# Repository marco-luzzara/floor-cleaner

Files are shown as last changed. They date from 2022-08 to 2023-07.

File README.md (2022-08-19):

# Floor Cleaner

This repo is made of 2 parts:

- the folder `app` contains the Python app to create and send the map for the cleaning
- the folder `cleaner` contains the C project for the STM32 Nucleo board that will take care of the cleaning procedure

---

## Protocol for Serial Communication

The app sends the map info through the `/dev/ttyACM0` serial device on Linux. These are the data sent throughout the procedure:

1. The character `&`, which represents the start (and the end) of the data flow
2. The number of rows in the grid
3. The character `|`, which is the separator character
4. The number of columns in the grid
5. The character `|`
6. From now on, every byte represents a cell in the grid, row by row from left to right: 
    - `1` stands for cell unavailable (to **not** clean)
    - `2` stands for cell that must be cleaned
    - `3` stands for the cleaner position (direction: up)
7. The character `&`

This is an example of data flow:

```
&3|4|211222231222&
```

For the following map:

```
░██░
░░░X
█░░░

░ = cell to clean
█ = cell to not clean
X = cleaner position
```

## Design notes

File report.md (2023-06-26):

# Floor Cleaner

The project consists of a floor cleaner, which is controlled by a Desktop Application. The user can draw a map on this app and the robot will try to go over each available cell in the map.

### Project Structure

The project root folder contains:

- The `app` folder with the Desktop application. Execute it with `./run.sh`
- The `cleaner` folder with the Nucleo board source code and the tests for the algorithm used. Note: the optimization level must be set to **2** (`-O2`): *Properties* -> *C/C++ Build* -> *Settings* -> *MCU GCC Compiler* -> *Optimization* -> Set to *Optimize more (-O2)*. The C standard used is **GNU11** (`-std=gnu11`): *Properties* -> *C/C++ Build* -> *Settings* -> *MCU GCC Compiler* -> *General* -> Set the Language standard to *GNU11 (...)*.

---

## Desktop Application

The Desktop application has been developped in Python with the support of PyQT6 for the graphical interface.

### Map Drawing
The map is represented by a grid of cells, each of these cover an area of 5cm * 5cm. There are 3 types of cells:

- UNAVAILABLE (grey in the grid): the cleaner should not go through it
- TO_CLEAN (blue in the grid): this cell must be cleaned in order to complete the cleaning procedure
- CLEANER_POSITION (black in the grid): the initial position of the cleaner

Initially, all cells are unavailable, but the user can mark them as to-clean by selecting them with a mouse press and release action. To place the cleaner in the map, search for the *Cleaner* label in the menu and then click on *Place Cleaner*. The next cell to be selected will be the cleaner position.

### Serial communication details
Once the map is ready, the user can connect the cleaner with an USB cable and go to *File* -> *Send* to start the sending procedure.

**Note**: it is important to connect the cleaner before opening the send dialog because it is initialized with the currently available ports:

```
from serial.tools import list_ports, list_ports_common

# ...

for i, serial_data in enumerate(list_ports.comports()):
    self._combo_box_serial.insertItem(
        i, serial_data.description, userData=serial_data)
```

After selecting the identifier for the Nucleo Board, the python app starts to transmit the bytes of the map with a baudrate of 9600.

### Map Transformation

The transmitted map is the smallest rectangle that includes all the to-clean cells in the grid. This means that there will never be a boundary row or column where all cells are unavailable.

Then the optimized grid is transformed into a matrix and each cell becomes a byte, in particular:

- UNAVAILABLE = 0x00
- TO_CLEAN = 0x01
- CLEANER_POSITION = 0x03

The 0x02 value does not exist yet but corresponds to the ALREADY_CLEANED value.

### Sending Protocol

In order for the map to be correctly interpreted by the Nucleo board, data are transmitted as bytes in the following order:

1. The character `&`, which represents the start (and the end) of the data flow
2. The number of rows in the map
3. The character `|`
4. The number of columns in the map
5. The character `|`
6. The map's cells, row by row from left to right
7. The character `&`

### Realtime Cleaning Window

Once the map has been sent, a new window opens, showing the drawn map. This map cannot be updated by the user, but is updated automatically by the messages that receives from the cleaner. After the user starts the cleaner, the latter will start sending messages about the new positions or obstacles on its way. See below for the messages format.

---

## Floor Cleaner

The cleaner will go through each to-clean cell in the received grid and avoids those that are marked as unavailable.

### Architecture and Components

During the development of the project, the architecture have changed. The main reason was to accomodate the window for the realtime updates of the cleaner.

The first architecture included the motors (wheels) and was externally power-sourced. It is described by this Fritzing schema:

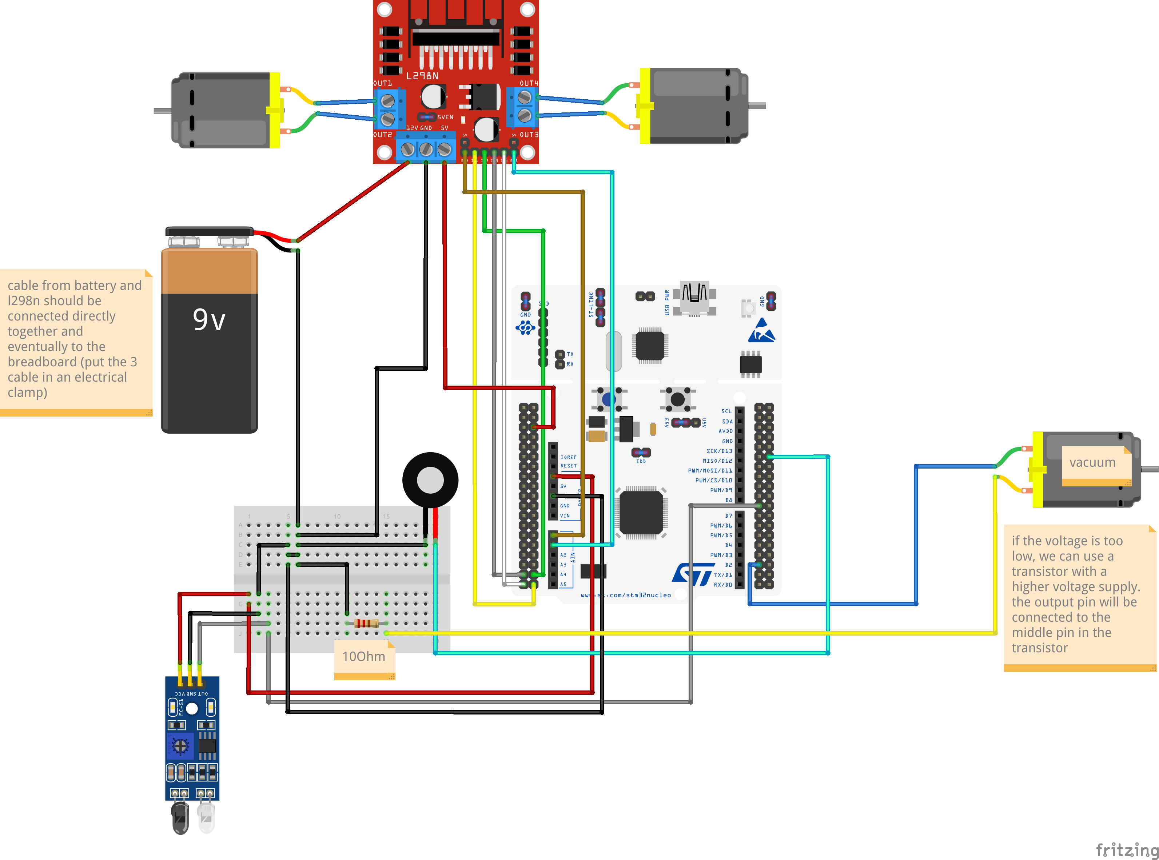
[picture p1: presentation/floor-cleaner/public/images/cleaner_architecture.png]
Architecture


#### Power Source
The power source consists of 2 batteries of 9V each, linked in parallel in order to increase the amperage. Each battery has an amperage of 1000mAh. Unfortunately, I have not found a light battery with a voltage of 12V, which would have increased the amount of components I could have added to the circuit.

#### L298N

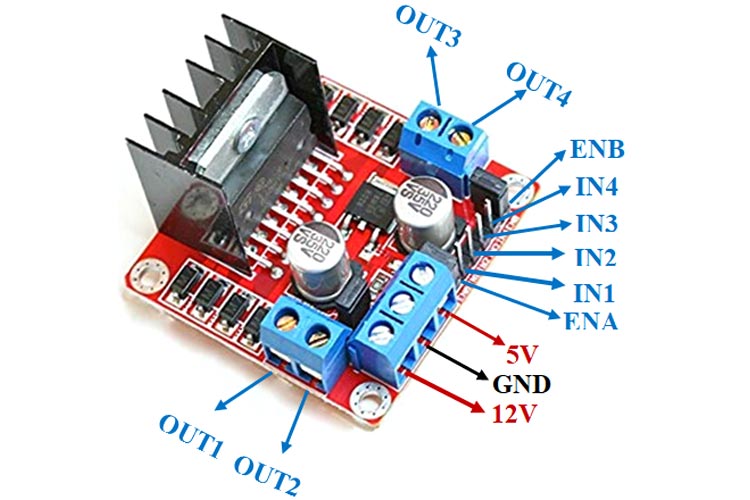
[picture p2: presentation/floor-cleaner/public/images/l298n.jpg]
L298N


This component is directly connected with the batteries and supplies power to:
- The 2 motors (wheels) using the output pins from OUT1 to OUT4
- The Nucleo board using the 5V pin, enabled via a jumper that regulates the input voltage

I can use the pins IN1-IN4 to control the motors direction, as described by the following table:

| IN1 | IN2 | Spinning direction |
| --- | --- | --- |
| 0 | 0 | Motor OFF |
| 0 | 1 | Backward |
| 1 | 0 | Forward |
| 1 | 1 | Motor OFF |

ENA and ENB are used to modulate the voltage that the output ports OUT1-OUT4 receive. These pins are connected to 2 PWM enabled pins, which are A0 and A1 in the Nucleo board.

#### IR Distance Sensor

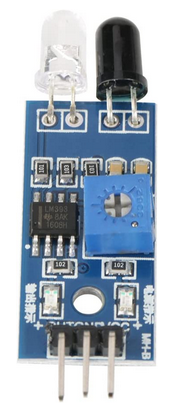
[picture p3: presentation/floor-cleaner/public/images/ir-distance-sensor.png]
IR distance sensor


The map is built by the user, but the cleaner might find some unpredictable obstacles on its way. To avoid any collisions, an IR distance sensor is used. This sensor has 3 pins:

- OUT: When a module detects an obstacle, the OUT port emits a low level signal that will be processed by the Nucleo board.
- GND
- VCC: this port is connected to the 3.3V pin of the Nucleo board

This component also has a potentiomenter that can adjust the IR sensor sensibility. Basically, it can detect obstacle from 2cm to 30cm, depending on the potentiometer value.

#### Buzzer

A buzzer informs the user about the cleaner's state:

- A single beep of 500ms: the cleaner is ready to receive a new map (and has successfully cleaned the previous map is present).
- 2 beeps of 500ms, interspersed by a beep of 300ms: the cleaner has received the map and is ready to drive
- 3 beeps of 300ms, interspersed by 2 beeps of 150ms: the cleaner has received an error while driving

---

### The Second Architecture 

The first architecture has some issues:

- The motors were not precise enough and a wheel could spin faster than the other. The motors were recycled from an old cleaner and each of them have a optical encoder mounted on it. I did not use it but it would have definitely improved the speed synchronization.
- 9V is probably too low to power-source the entire cleaner, the original battery was 14V.
- The window for realtime update was not possible because the cleaner moves freely and cannot be attached to the USB cable.

The second architecture is conceptually very similar to the previous one because the only difference is that it is power-sourced directly from the USB and the L298N connections have been replaced with LEDs. The only additional component is a LCD display that shows informational messages.

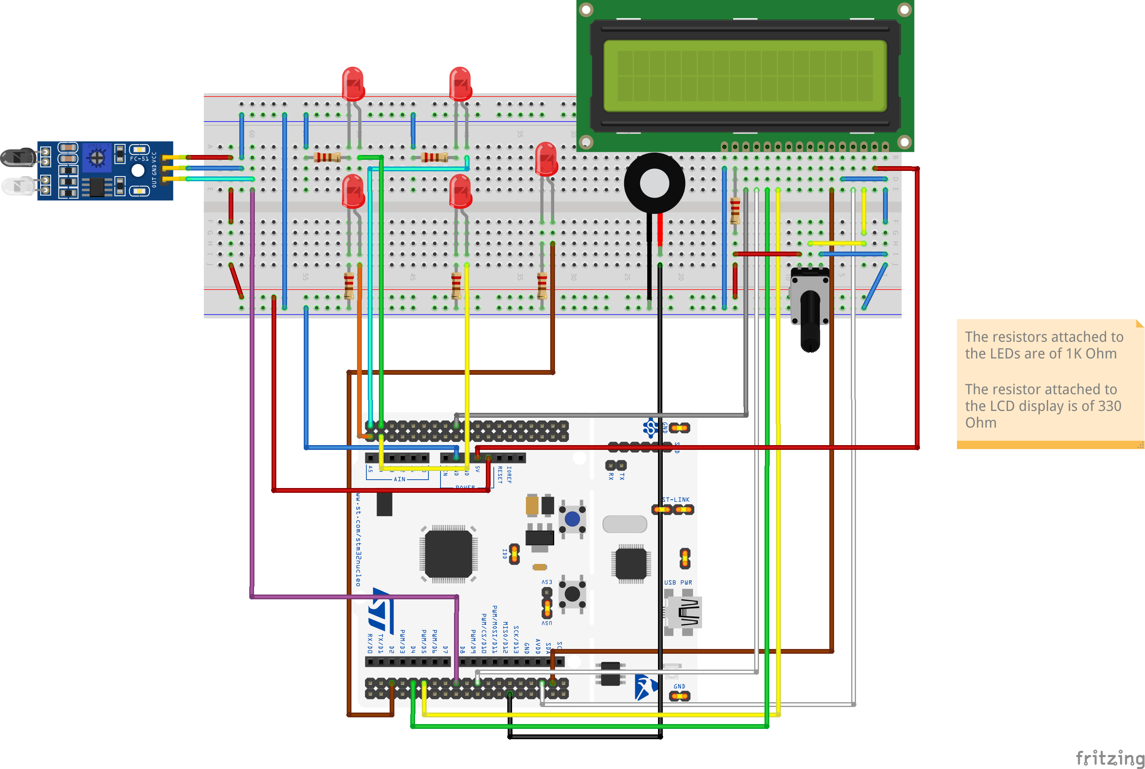
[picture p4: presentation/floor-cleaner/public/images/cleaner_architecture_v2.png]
Architecture v2


#### LCD Display

The LCD display is a 1602A LCD, that I have set on 4-bit mode. I have also used a potentiometer to adjust the screen brightness.

---

### Map Processing

The cleaner receives the map from the UART pin PA3. I have used the polling mode because the cleaner does not need to do anything else in the meanwhile.

The reading process is optimized to speed up the data saving. In fact, after reading the `row_count` and `column_count`, I allocate 2 arrays:

- `(CellType**) map_rows`: one of size `row_count` that contains the pointers to the map rows
- `(CellType*) map`: another one of size `row_count * column_count` containing the map cells

Assuming to have a map of 3 rows and 2 columns, this is how the 2 arrays are filled:

```

map:                                ┌───┬───┐
                      ┌───────────> │   │   │
                      │             ├───┼───┤
                      │   ┌───────> │   │   │
                      │   │         ├───┼───┤
                      │   │   ┌───> │   │   │
                      │   │   │     └───┴───┘
                      │   │   │
                      │   │   │
                      │   │   │
                    ┌───┬───┬───┐
map_rows:           │   │   │   │
                    └───┴───┴───┘
```

In this way, I can read the entire map at once by passing the `map` array as buffer. I am sure that the `map` array is a continuous block of memory, but I can access it through the `map_rows` array because it contains the pointers to the map rows.

The map data are placed in a struct of type `MapInfo`:

```
typedef struct MapInfo {
	uint8_t** map;
	uint16_t row_count;
	uint16_t column_count;
} MapInfo;
```

---

### Driving Preparation

Once the cleaner has received the entire map, the user can instruct the cleaner to start by pressing the user button on the Nucleo board. After about 1 second, the `start_drive` method is called and the cleaner will start driving:

```
HAL_TIM_Base_Start(&htim2); // Init PWM for motors' speed modulation
HAL_TIM_PWM_Start(&htim2, TIM_CHANNEL_1);
HAL_TIM_PWM_Start(&htim2, TIM_CHANNEL_2);

MotorsInfo motorsInfo = {
		.left1_GPIOType = MOTOR_1___IN1_GPIO_Port, .left1_pin = MOTOR_1___IN1_Pin,
        // ...
};
CleanComponentsInfo cleanComponentsInfo = { .vacuum_GPIOType = VACUUM_GPIO_Port, .vacuum_pin = VACUUM_Pin };
is_driving = true;
int result_code = start_drive(&mapInfo, &is_obstacle_found, &motorsInfo, &cleanComponentsInfo);
```

The `start_drive` method expects a list of struct that contains the components info, as well as a boolean flag, which is `is_obstacle_found`, that will be explained later.

As for the `result_code`, the only successful return code is 0, whereas the other are interpreted as error codes.

#### Cleaner Initialization

Before starting to clean, I initialize the `CleanerInfo` struct with its initial position in the map and its direction, that by default is `UP`. If the cleaner position cannot be found in the map, the `start_drive` returns 1.

#### Move Cleaner to the Start Position

For simplicity, the cleaner will always start cleaning from the top-left cell of the map, or to the one nearest to it if the top-left one is unavailable. The details on how the cleaner reaches the initial position are described later in the part dedicated to the driving algorithm.

If the initial position cannot be found or the cleaner cannot reach it, then the codes returned are 2 and 3, respectively.

---

### The Cleaning Algorithm

The cleaner will clean the entire area of the map starting from the top-left cell that must be clean and proceeding to the right. The logic is very simple: the cleaner will always maintain an unavailable cell on its left. In this way, it starts from the perimeter and progressively reaches the center of the area.

For the simplest case (a rectangle/square), the path that the cleaner follows is indicated by the dashed line:

```
┌───┬───┬───┬───┐
│ --│---│---│-┐ │
├───┼───┼───┼───┤
│ ┌-│---│-> │ │ │
├───┼───┼───┼───┤
│ └-│---│---│-┘ │
└───┴───┴───┴───┘
```

As far as the next cell to clean is adjacent to the current one, the next cell position can be easily computed by inspecting the surrounding cells. However, it is not always possible to have such a linear path, for example with this map:

```
┌───┬───┐   ┌───┬───┐
│---│-┐ │   │ ┌-│->?│
├───┼───┼───┼───┼───┘
│   │ └-│---│-┘ │
├───┼───┼───┼───┤
│   │   │   │   │
└───┴───┴───┴───┘
```

Once the cleaner reaches the top-right cell, there is no adjacent cell available. In this case, I need to search for the nearest reachable cell that is marked as to-clean, then I need a path-finding algorithm that can take the cleaner there.

The algorithm that looks for the nearest reachable cell firstly visit the square of cells that surround the current cell. If it does not find any to-clean cell, then it extends the radius of the square by 1 and so on until it finds a reachable cell (or until all the area has been cleaned). For example, in the following map:

```
┌───┬───┐   ┌───┬───┐
│ X │ X │   │ X │ C │
├───┼───┼───┼───┼───┘
│   │ X │ X │ X │
├───┼───┼───┼───┤
│   │   │   │ N │
└───┴───┴───┴───┘

C = cleaner
X = unavailable
N = next position
```

The target position (`N`) is the first one available while visiting the square of radius 2 from the cleaner position. In the next map I represented the order of visit of the cells around `C` (actually, some rows and columns are discarded in advanced, like those outside the map boundaries).

```
┌---┬---┬---┬---┬---┐
| 9 | 10| 11| 12| 13|
├---┼---┼---┼---┼---┤
|   | 1 | 2 | 3 | 14|
├---┼───┼───┼---┼---┤
|   │ 8 │ C │ 4 | 15|
├───┼───┼───┼---┼---┤
│   │ 7 │ 6 | 5 | 16|
├───┼───┼---┼---┼---┤
│   │ 20│ 19| 18| 17|
└───┴───┴---┴---┴---┘
```

The path to the target cell, which is the one having `id = 20`, is found by the path-finding algorithm. The one I have chosen is the A* and the current implementation can be found on [this page](https://github.com/BigZaphod/AStar).

While crossing the path from a cell to a non-adjacent cell, the cleaner disables the brush because it likely crosses only already-cleaned cells. This optimization is supposed to saves some energy. The driving algorithm stops when there is no more cell to clean or when an error occurs.

---

### Cleaner Movements

There are 3 methods that control the motors that move the cleaner. 

`drive_forward` moves the cleaner of one cell along the current direction: 

```
static bool drive_forward(CleanerInfo* cleanerInfo, bool* obstacle_found, MotorsInfo* motorsInfo) {
	*obstacle_found = false;
	bool undo_drive = false;
	bool was_target_reached;
    // ...
```

`obstacle_found` is a global variable that is set when the IR distance sensor detects an obstacle. This is necessary to stop the cleaner and avoid the collision.

```
    // ...
#ifndef __TESTING__
    HAL_NVIC_EnableIRQ(EXTI4_15_IRQn);

	HAL_GPIO_WritePin(motorsInfo->left2_GPIOType, motorsInfo->left2_pin, GPIO_PIN_SET); // ACW
	HAL_GPIO_WritePin(motorsInfo->right1_GPIOType, motorsInfo->right1_pin, GPIO_PIN_SET); // CW
    uint32_t tickstart = HAL_GetTick();
    uint32_t wait = millis_to_drive;
    uint32_t undo_delay;

    while((undo_delay = HAL_GetTick() - tickstart) < wait)
    {
    	if (*obstacle_found) {
    		undo_drive = true;
    		break;
    	}
    }

    HAL_GPIO_WritePin(motorsInfo->left2_GPIOType, motorsInfo->left2_pin, GPIO_PIN_RESET);
    HAL_GPIO_WritePin(motorsInfo->right1_GPIOType, motorsInfo->right1_pin, GPIO_PIN_RESET);
#endif
    // ...
```

The above code is modified from the `HAL_Delay()` method because I need to wait for `millis_to_drive` milliseconds while the motors spin and move the cleaner. However, I could need to stop the cleaner early in case of obstacle, which would set the `undo_drive` flag.

```

    if (!undo_drive) {
    	uint16_t current_row = cleanerInfo->position.row;
    	uint16_t current_col = cleanerInfo->position.col;

    	switch (cleanerInfo->direction) {
    	case UP: current_row--; break;
    	case RIGHT: current_col++; break;
    	case DOWN: current_row++; break;
    	case LEFT: current_col--; break;
    	}

    	cleanerInfo->position.row = current_row;
    	cleanerInfo->position.col = current_col;

        was_target_reached = true;
    }
    else {
#ifndef __TESTING__
        // drive backward because of obstacle
        HAL_GPIO_WritePin(motorsInfo->left1_GPIOType, motorsInfo->left1_pin, GPIO_PIN_SET); // CW
    	HAL_GPIO_WritePin(motorsInfo->right2_GPIOType, motorsInfo->right2_pin, GPIO_PIN_SET); // ACW

    	// TODO: what if an obstacle is found while going back
        HAL_Delay(undo_delay);

        HAL_GPIO_WritePin(motorsInfo->left1_GPIOType, motorsInfo->left1_pin, GPIO_PIN_RESET);
    	HAL_GPIO_WritePin(motorsInfo->right2_GPIOType, motorsInfo->right2_pin, GPIO_PIN_RESET);
#endif

        was_target_reached = false;
    }

#ifndef __TESTING__
    HAL_NVIC_DisableIRQ(EXTI4_15_IRQn);
#endif

	return was_target_reached;
}
```

Here I have 2 possible outcomes: the `undo_drive` is set, it is not. In the former case, the cleaner must move backwards and will mark the target cell as unavailable because of the obstacle found. In this case, the motors spin backwards for `undo_delay` milliseconds, which corresponds to the same time spent by the cleaner in trying to reach the target cell. When the `undo_drive` flag is clear, then the cleaner position is updated

The other 2 methods to move the cleaner are `turn_left` and `turn_right`, but do not move the cleaner to another cell, they simply change its direction. The cleaner rotates clockwise or anticlockwise around its center. Here the code for the `turn_left`:

```
static void turn_left(CleanerInfo* cleanerInfo, MotorsInfo* motorsInfo) {
#ifndef __TESTING__
	HAL_GPIO_WritePin(motorsInfo->left1_GPIOType, motorsInfo->left1_pin, GPIO_PIN_SET); // CW
	HAL_GPIO_WritePin(motorsInfo->right1_GPIOType, motorsInfo->right1_pin, GPIO_PIN_SET); // CW

	HAL_Delay(millis_to_turn);

	HAL_GPIO_WritePin(motorsInfo->left1_GPIOType, motorsInfo->left1_pin, GPIO_PIN_RESET);
	HAL_GPIO_WritePin(motorsInfo->right1_GPIOType, motorsInfo->right1_pin, GPIO_PIN_RESET);
#endif

	// adding 3 is like subtracting 1 with modulo 4
	cleanerInfo->direction = (cleanerInfo->direction + 3) % 4;
}
```

The `__TESTING__` regions are created to disable the enclosing code when the `__TESTING__` directive is set.

---

### Obstacle Detection

When an obstacle is detected, the distance sensor emits a low signal that the `PA9` pin intercepts and processes. Pin `PA9` works in interrupt mode and the callback globally sets the `obstacle_found` flag:

```
void HAL_GPIO_EXTI_Callback(uint16_t GPIO_Pin)
{
	if(GPIO_Pin == GPIO_PIN_9 && is_driving) // If The INT Source Is EXTI Line9 (A9 Pin)
	{
		HAL_NVIC_DisableIRQ(EXTI4_15_IRQn);
		is_obstacle_found = true;
	}
}
```

This interrupt is enabled when the `drive_forward` method is called and disabled at the end of it. Afterall, the obstacle sensor is useful only when the cleaner moves in the current direction, not even when it turns left or right because its position does not change.

---

### Realtime Updates

After the map has been sent and the cleaner starts, each new position and obstacle found in the cleaner's way are communicated to the Desktop application using the serial interface. 4 types of messages will be sent:

- `START{}`: it is the first message the cleaner sends and indicates that the cleaner started cleaning
- `MOVE{'r':1,'c':2,'cleaning_enabled':true}`: it is sent when the cleaner moves to a new cell. This command has 3 parameters: the row and column of the new cell and `cleaning_enabled`, that specifies whether it is currently cleaning. The cleaner will not clean cells where it has already cleaned.
- `OBSTACLE{'r':1,'c':2}`: it is sent when a cleaner encounters an obstacle, the parameters are the obstacle position
- `END{'ret_code':0}`: it is the last message to be sent and also specifies the return code (0 if the cleaning was successful, > 0 otherwise).

Depending on the message received, the Desktop application updates the realtime map. In particular, the cleaned cells get colored of green, while obstacles get colored of red.

---

### Testing the Algorithm

It is possible to test the driving algorithm exclusively by compiling with a slightly different option: `-D__TESTING__`. This directive hides all the `HAL_` calls and the tests just verify that, at the end, the to-clean cells have been actually cleaned. The code enclosed in the `#ifndef __TESTING__` regions is not compiled because it contains superfluous calls for the algorithm testing.

The testing library is [minunit](https://github.com/siu/minunit) and tests can be run with `make run`.

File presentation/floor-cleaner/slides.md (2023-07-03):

---
# try also 'default' to start simple
theme: default
# apply any windi css classes to the current slide
class: 'text-center'
# https://sli.dev/custom/highlighters.html
highlighter: shiki
# show line numbers in code blocks
lineNumbers: false
# persist drawings in exports and build
drawings:
  persist: false
# page transition
transition: slide-left
# use UnoCSS
css: unocss
layout: cover
---

# Floor Cleaner

---

## Overview

<v-clicks>

  - **What** 
    * A floor cleaner that cleans an area represented by a map, which is drawn in a Desktop App
  - **How**
    * Python App for the map drawing
    * The Nucleo-L053R8 controls the cleaner
</v-clicks>

---
layout: image-right
image: ./images/app-create-map.png
---

## Python App (Map)

<v-clicks>

- Each cell represents a small area that the cleaner can clean by just passing on it 
- A blue cell must be cleaned, a grey cell is like a virtual wall
- The black cell represents the position of the cleaner

</v-clicks>

---

## Python App (Map Conversion)

<div class="grid grid-rows-1 grid-cols-3 grid-flow-col centered-grid gap-x-10">

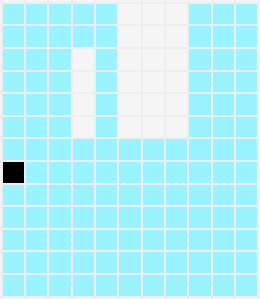
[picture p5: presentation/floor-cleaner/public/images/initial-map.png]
Initial Map
  

  <material-symbols-arrow-right-alt-rounded class="text-5xl"/>

  ```
  { 1, 1, 1, 1, 1, 0, 0, 0, 1, 1, 1,
    1, 1, 1, 1, 1, 0, 0, 0, 1, 1, 1,
    1, 1, 1, 0, 1, 0, 0, 0, 1, 1, 1,
    1, 1, 1, 0, 1, 0, 0, 0, 1, 1, 1,
    1, 1, 1, 0, 1, 0, 0, 0, 1, 1, 1,
    1, 1, 1, 0, 1, 0, 0, 0, 1, 1, 1,
    1, 1, 1, 1, 1, 1, 1, 1, 1, 1, 1,
    3, 1, 1, 1, 1, 1, 1, 1, 1, 1, 1,
    1, 1, 1, 1, 1, 1, 1, 1, 1, 1, 1,
    1, 1, 1, 1, 1, 1, 1, 1, 1, 1, 1,
    1, 1, 1, 1, 1, 1, 1, 1, 1, 1, 1,
    1, 1, 1, 1, 1, 1, 1, 1, 1, 1, 1,
    1, 1, 1, 1, 1, 1, 1, 1, 1, 1, 1 }
  ```

</div>

---

## Python App (Map Sending)

The Python app detects the Nucleo board, which is connected through USB, and starts sending the map:

```python {all|1|2|3-6|8-10|12|all}
with serial.Serial(port=serial_data.device, baudrate=9600) as cleaner_serial:
    cleaner_serial.write(b'&')
    cleaner_serial.write(bytes(str(len(cleaning_map)), encoding='ascii'))
    cleaner_serial.write(b'|')
    cleaner_serial.write(bytes(str(len(cleaning_map[0])), encoding='ascii'))
    cleaner_serial.write(b'|')

    for row in cleaning_map:
        for cell in row:
            cleaner_serial.write(cell.value.to_bytes(1, byteorder='big'))

    cleaner_serial.write(b'&')
```

---

## Cleaner Architecture (Version 1)

<div class="flex gap-x-10">
<div class="drawable-container">
  

  <EmptyCircle xcenter="8%" ycenter="22%" width="21%" height="33%" for="battery" v-if="$slidev.nav.clicks === 1" />
  <EmptyCircle xcenter="29%" ycenter="-5%" width="21%" height="30%" for="l298n" v-if="$slidev.nav.clicks === 2" />
  <EmptyCircle xcenter="8%" ycenter="75%" width="16%" height="25%" for="distance-sensor" v-if="$slidev.nav.clicks === 3" />
  <EmptyCircle xcenter="85%" ycenter="45%" width="16%" height="20%" for="vacuum" v-if="$slidev.nav.clicks === 4" />
  <EmptyCircle xcenter="11%" ycenter="3%" width="17%" height="20%" for="left-wheel" v-if="$slidev.nav.clicks === 5" />
  <EmptyCircle xcenter="51%" ycenter="3%" width="17%" height="20%" for="right-wheel" v-if="$slidev.nav.clicks === 6" />
  <EmptyCircle xcenter="32%" ycenter="48%" width="10%" height="14%" for="buzzer" v-if="$slidev.nav.clicks === 7" />
  
</div>

<v-clicks>

  - Battery
  - L298N
  - Distance Sensor
  - Vacuum
  - Left wheel
  - Right wheel
  - Buzzer

</v-clicks>

</div>

---

## Power Source

<div class="flex centered-flex gap-x-10">

  

  <div v-show="[2, 3].includes($slidev.nav.clicks)" class="flex centered-flex gap-x-10">
  <material-symbols-arrow-circle-right-rounded class="text-5xl" />
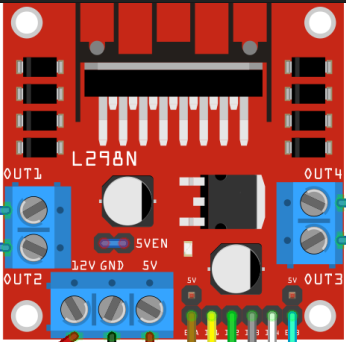
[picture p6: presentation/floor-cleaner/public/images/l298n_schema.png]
  
  </div>

  <div v-show="$slidev.nav.clicks === 3" class="flex centered-flex gap-x-10">
  <material-symbols-arrow-circle-right-rounded class="text-5xl" />
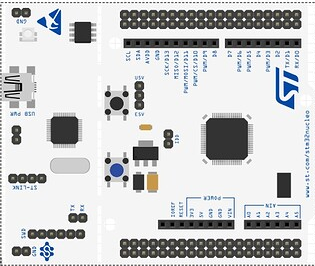
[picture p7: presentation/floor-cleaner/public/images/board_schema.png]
  
  </div>

</div>

<v-clicks class="m-10">

  - 9V/1A battery
  - L298N
  - STM32 Board power-supplied by the E5V source

</v-clicks>

---

## L298N

<div class="flex gap-x-10">
<div class="drawable-container">
  

  <EmptyCircle xcenter="13%" ycenter="75%" width="27%" height="25%" for="12v-and-ground" v-if="$slidev.nav.clicks === 1" />
  <EmptyCircle xcenter="83%" ycenter="52%" width="18%" height="26%" for="wheel-ports" v-if="$slidev.nav.clicks === 2" />
  <EmptyCircle xcenter="0%" ycenter="53%" width="18%" height="26%" for="wheel-ports" v-if="$slidev.nav.clicks === 2" />
  <EmptyCircle xcenter="35%" ycenter="77%" width="16%" height="23%" for="board-power-source" v-if="$slidev.nav.clicks === 3" />
  <EmptyCircle xcenter="50%" ycenter="77%" width="40%" height="23%" for="in-ports" v-if="$slidev.nav.clicks === 4" />
  
</div>

<v-clicks>

  - 12V and Ground ports
  - Out ports (wheels)
  - Board source power
  - Input ports and PWM ports

</v-clicks>

</div>

---

## Distance Sensor

<div class="flex gap-x-10">
<div class="drawable-container">
  

  <EmptyCircle xcenter="20%" ycenter="80%" width="24%" height="20%" for="out" v-if="$slidev.nav.clicks === 1" />
  <EmptyCircle xcenter="36%" ycenter="80%" width="24%" height="20%" for="gnd" v-if="$slidev.nav.clicks === 2" />
  <EmptyCircle xcenter="51%" ycenter="80%" width="24%" height="20%" for="vcc" v-if="$slidev.nav.clicks === 3" />
  <EmptyCircle xcenter="45%" ycenter="40%" width="45%" height="25%" for="potentiometer" v-if="$slidev.nav.clicks === 4" />
  <EmptyCircle xcenter="15%" ycenter="-3%" width="78%" height="33%" for="ir" v-if="$slidev.nav.clicks === 5" />
  
</div>

<v-clicks>

- OUT
- GND
- 3.3V
- Potentiometer
- Infrared emitter/receiver

</v-clicks>
</div>

---
layout: image-right-fit
image: ./images/cleaner_mounted_v1.png
---

## Cleaner Architecture (Issues and Limits)

This cleaner architecture has some issues/limitations:

<v-clicks>

- The motors are not precise enough (optical encoders mitigated this issue)
- 9V is a too low voltage to power source the entire circuit. The original battery was 14V.
- **Limited communication with the Desktop Application**

</v-clicks>

---

## Cleaner Architecture (Version 2)

<div class="flex gap-x-10">
<div class="drawable-container">
  

  <EmptyCircle xcenter="-3%" ycenter="14%" width="24%" height="16%" for="distance-sensor" v-if="$slidev.nav.clicks === 1" />
  <EmptyCircle xcenter="43%" ycenter="15%" width="10%" height="15%" for="vacuum" v-if="$slidev.nav.clicks === 2" />
  <EmptyCircle xcenter="27%" ycenter="17%" width="17%" height="20%" for="left-wheel" v-if="$slidev.nav.clicks === 3" />
  <EmptyCircle xcenter="27%" ycenter="4%" width="17%" height="20%" for="right-wheel" v-if="$slidev.nav.clicks === 4" />
  <EmptyCircle xcenter="52.5%" ycenter="18%" width="9%" height="13%" for="buzzer" v-if="$slidev.nav.clicks === 5" />
  <EmptyCircle xcenter="43%" ycenter="-3%" width="45%" height="25%" for="lcd" v-if="$slidev.nav.clicks === 6" />
  
</div>

<v-clicks>

  - Distance Sensor
  - Vacuum
  - Left wheel
  - Right wheel
  - Buzzer
  - LCD Display

</v-clicks>

</div>

---

## LCD Display

<v-clicks>

- It is a 1602A LCD display, that I have set on 4-bit mode
- The potentiometer is used to adjust the screen brightness
- It shows the cleaner's actions or informational messages

</v-clicks>

---

## Cleaning Procedure

<div style="width: 100%; text-align: center">

```mermaid {scale: 0.8}
flowchart TB
  start(((start)))
  waitForMap["The buzzer emits a signal for 500ms
    The cleaner is ready to receive the map"]
  mapReceived["The cleaner receives the map and saves it
    Emits 2 signals of 500ms each"]
  userButtonPressed["The user press the User button
    After 1 second the cleaner starts cleaning"]
  errorWhileCleaning?{"Any error
    occurred?"}
  errorSignal[The buzzer emits 3 quick signal]

  start --> waitForMap
  waitForMap --> mapReceived
  mapReceived --> userButtonPressed
  userButtonPressed --> errorWhileCleaning?
  errorWhileCleaning? -->|Yes| errorSignal --> waitForMap
  errorWhileCleaning? -->|No| waitForMap
  
```

</div>

---

## Map Saving

<v-clicks>

- Store the `row_count`
- Store the `column_count`
- Allocate 2 arrays:
  - `(CellType**) map_rows`: one of size `row_count` that contains the pointers to the map rows
  - `(CellType*) map`: another one of size `row_count * column_count` containing the map cells
- Read the entire map in one shot:
  ```c
  HAL_UART_Receive(huart, map, row_count * column_count, HAL_MAX_DELAY);
  ```

</v-clicks>

---

## Cleaning Algorithm

<div class="grid centered-grid grid-rows-2 grid-cols-2 gap-x-20">

<div class="path grid grid-rows-3 grid-cols-4">
  <Cell from="right" />
  <Cell from="left" to="right" />
  <Cell from="left" to="right" />
  <Cell from="left" to="down" />
  <Cell from="down" to="right" />
  <Cell from="left" to="right" />
  <Cell from="left" />
  <Cell from="up" to="down" />
  <Cell from="right" to="up" />
  <Cell from="right" to="left" />
  <Cell from="right" to="left" />
  <Cell from="up" to="left" />
</div>

<div class="path grid grid-rows-3 grid-cols-4">
  <Cell from="down" />
  <Cell invisible="true" />
  <Cell from="down" to="right" />
  <Cell from="left" to="down" />
  <Cell from="up" to="right" />
  <Cell from="left" to="right" />
  <Cell from="left" to="up" />
  <Cell from="up" centerContent="?" />
  <Cell />
  <Cell />
  <Cell />
</div>

**Simple case**: the cleaner never moves to an already-cleaned cell

**Complex case**: the cleaner moves to a cell surrounded by only unavailable or already-cleaned cells

</div>

<style>
  .path {
    width: 12em;
    height: 9em;
  }
</style>

---

## Cleaning Algorithm (Non-adjacent Cell Search)

<div class="flex centered-flex">

<div id="path_complex" class="grid grid-rows-3 grid-cols-5">
  <Cell color="#9BF3FF" />
  <Cell invisible="true" />
  <Cell color="#9BF3FF" textColor="black" centerContent="1" />
  <Cell color="#9BF3FF" textColor="black" centerContent="2"/>
  <Cell isDashed="true" centerContent="3"/>
  <Cell color="#9BF3FF" />
  <Cell color="#9BF3FF" />
  <Cell color="#9BF3FF" />
  <Cell color="#9BF3FF" textColor="black" centerContent="C" />
  <Cell isDashed="true" centerContent="4"/>
  <Cell />
  <Cell />
  <Cell centerContent="7"/>
  <Cell isDashed="true" centerContent="6"/>
  <Cell isDashed="true" centerContent="5"/>
</div>

</div>

<v-clicks>

- **C** is the cleaner position
- light blue cells have already been cleaned
- The search order is defined by the squares of edge 3, 5, 7 etc that enclose the current cell
- The target cell is the first non-cleaned cell found

</v-clicks>

<style>
  #path_complex {
    width: 15em;
    height: 9em;
  }
</style>

---

## Moving to the Non-adjacent Cell

<v-clicks>

- The path to the target cell is created by the [A* Algorithm](https://github.com/BigZaphod/AStar)
- During the time from the current to the target cell, the cleaner will not clean

</v-clicks>

---

## Cleaner Movements (#1)

While driving forward, the cleaner checks for obstacles:

```c {all|1-3|5|8,9|11-21|23,24|all}
*obstacle_found = false;
bool undo_drive = false;
bool was_target_reached;

HAL_NVIC_EnableIRQ(EXTI4_15_IRQn);

// modified from HAL_Delay(Delay)
HAL_GPIO_WritePin(motorsInfo->left2_GPIOType, motorsInfo->left2_pin, GPIO_PIN_SET); // ACW
HAL_GPIO_WritePin(motorsInfo->right1_GPIOType, motorsInfo->right1_pin, GPIO_PIN_SET); // CW

uint32_t tickstart = HAL_GetTick();
uint32_t wait = millis_to_drive;
uint32_t undo_delay;

while((undo_delay = HAL_GetTick() - tickstart) < wait)
{
  if (*obstacle_found) {
    undo_drive = true;
    break;
  }
}

HAL_GPIO_WritePin(motorsInfo->left2_GPIOType, motorsInfo->left2_pin, GPIO_PIN_RESET);
HAL_GPIO_WritePin(motorsInfo->right1_GPIOType, motorsInfo->right1_pin, GPIO_PIN_RESET);

// ...
```

<style> 
  .slidev-layout {
    --slidev-code-font-size: 0.6rem;
    --slidev-code-line-height: calc(0.6rem * 1.5); 
  }
</style> 

---

## Cleaner Movements (#2)

```c{all|2|3-11|12-25|28|all}
MapPosition next_position;
get_next_position_while_driving_forward(cleanerInfo, &next_position);
if (!undo_drive) {
  cleanerInfo->position.row = next_position.row;
  cleanerInfo->position.col = next_position.col;

  was_target_reached = true;

  send_new_cleaner_position_command(huart, cleanerInfo->position.row, cleanerInfo->position.col, cleaning_enabled);
  Lcd_clear_and_write(lcd, "Going forward");
}
else {
  // drive backward because of obstacle
  HAL_GPIO_WritePin(motorsInfo->left1_GPIOType, motorsInfo->left1_pin, GPIO_PIN_SET); // CW
  HAL_GPIO_WritePin(motorsInfo->right2_GPIOType, motorsInfo->right2_pin, GPIO_PIN_SET); // ACW

  HAL_Delay(undo_delay);

  HAL_GPIO_WritePin(motorsInfo->left1_GPIOType, motorsInfo->left1_pin, GPIO_PIN_RESET);
  HAL_GPIO_WritePin(motorsInfo->right2_GPIOType, motorsInfo->right2_pin, GPIO_PIN_RESET);

  send_obstacle_command(huart, next_position.row, next_position.col);
  Lcd_clear_and_write(lcd, "Obstacle found");

  was_target_reached = false;
}

HAL_NVIC_DisableIRQ(EXTI4_15_IRQn);
return was_target_reached;
```

<style> 
  .slidev-layout {
    --slidev-code-font-size: 0.6rem;
    --slidev-code-line-height: calc(0.6rem * 1.5); 
  }
</style> 

---

## Distance Sensor

If an obstacle is detected, the interrupt is disabled until the next `drive_forward` command

```c{all|5,6|all}
void HAL_GPIO_EXTI_Callback(uint16_t GPIO_Pin)
{
	if(GPIO_Pin == GPIO_PIN_9 && is_driving) // If The INT Source Is EXTI Line9 (A9 Pin)
	{
		HAL_NVIC_DisableIRQ(EXTI4_15_IRQn);
		is_obstacle_found = true;
	}
}
```

---

## Realtime Updates

The cleaner, once started, sends update messages to the Desktop Application. These messages are used to show the cleaning status.

The messages are:

<v-clicks>

- `START{}`
- `MOVE{'r':1,'c':2,'cleaning_enabled':true}`
- `OBSTACLE{'r':1,'c':2}`
- `END{'ret_code':0}`

</v-clicks>

---

## Updates Transmission

Every message is sent asynchronously with the DMA:

```c{all|1|8|10|all}
while (__HAL_UART_GET_FLAG(huart, UART_FLAG_TC) != SET);

uint8_t current_command_size = strlen(raw_command);
uint8_t final_command_size = current_command_size + 1; // 1 is for the \n

memset(buf, 0, sizeof(buf));
strcat(buf, raw_command);
buf[current_command_size] = '\n';

HAL_UART_Transmit_DMA(huart, (uint8_t *) buf, final_command_size);
```

---

## Testing

The cleaning algorithm has been tested independently using a different configuration:

<v-clicks>

- The entry point is `Src/tests/driving_test.c`, compiled with a custom `Makefile`
- The `TESTING` macro is enabled and hides all the MCU-specific code (including the obstacle detection logic)
- I have used `min_unit.h` as testing library

</v-clicks>

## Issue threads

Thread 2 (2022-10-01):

Convert A* to a Memory bounded version

marco-luzzara, 2022-10-01:
A* is currently used to find the shortest path in the grid, when the cleaner needs to move to another area.
in the worst case, A* needs exponential memory storage. It is not feasible in an embedded environment given the limited memory availability. A possible solution is to use SMA* (Simplified Memory-Bounded A*), see

[https://it.wikipedia.org/wiki/SMA*](https://it.wikipedia.org/wiki/SMA*)
[https://laconicml.com/simplified-memory-bounded-a-star/](https://laconicml.com/simplified-memory-bounded-a-star/)
[https://stackoverflow.com/questions/38554515/most-memory-efficient-algorithm-for-finding-a-path-on-a-grid](https://stackoverflow.com/questions/38554515/most-memory-efficient-algorithm-for-finding-a-path-on-a-grid)

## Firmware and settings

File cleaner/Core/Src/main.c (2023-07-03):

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
/* Includes ------------------------------------------------------------------*/
#include "main.h"

/* USER CODE BEGIN Includes */
#include <string.h>
#include <stdlib.h>
#include <stdbool.h>
#include "types/map.h"
#include "types/cleaner.h"
#include "map_communication.h"
#include "driving.h"
#include "lcd.h"
/* USER CODE END Includes */

TIM_HandleTypeDef htim2;

UART_HandleTypeDef huart2;
DMA_HandleTypeDef hdma_usart2_tx;

/* USER CODE BEGIN PV */

static void set_buzzer(int millisec) {
	HAL_GPIO_WritePin(BUZZER_GPIO_Port, BUZZER_Pin, GPIO_PIN_SET);
	HAL_Delay(millisec);
	HAL_GPIO_WritePin(BUZZER_GPIO_Port, BUZZER_Pin, GPIO_PIN_RESET);
}

static void signal_cleaner_ready_for_map_receiving() {
	set_buzzer(500);
}

static void signal_map_received() {
	set_buzzer(500);
	HAL_Delay(300);
	set_buzzer(500);
}

static void signal_cleaner_error() {
	set_buzzer(300);
	HAL_Delay(150);
	set_buzzer(300);
	HAL_Delay(150);
	set_buzzer(300);
}

/* USER CODE END PV */

void SystemClock_Config(void);
static void MX_GPIO_Init(void);
static void MX_USART2_UART_Init(void);
static void MX_DMA_Init(void);
static void MX_TIM2_Init(void);
/* USER CODE BEGIN 0 */

Lcd_HandleTypeDef lcd;
bool is_obstacle_found = false;
bool is_driving = false;

/* USER CODE END 0 */

/**
  * @brief  The application entry point.
  * @retval int
  */
int main(void)
{
  /* MCU Configuration--------------------------------------------------------*/

  /* Reset of all peripherals, Initializes the Flash interface and the Systick. */
  HAL_Init();

  /* Configure the system clock */
  SystemClock_Config();

  /* Initialize all configured peripherals */
  MX_DMA_Init();
  MX_GPIO_Init();
  MX_USART2_UART_Init();
  MX_TIM2_Init();
  /* USER CODE BEGIN 2 */

  // https://www.micropeta.com/video60
	// Lcd_PortType ports[] = { D4_GPIO_Port, D5_GPIO_Port, D6_GPIO_Port, D7_GPIO_Port };
	Lcd_PortType lcd_ports[] = { D4_GPIO_Port, D5_GPIO_Port, D6_GPIO_Port, D7_GPIO_Port };
	// Lcd_PinType pins[] = {D4_Pin, D5_Pin, D6_Pin, D7_Pin};
	Lcd_PinType lcd_pins[] = { D4_Pin, D5_Pin, D6_Pin, D7_Pin };
	// Lcd_create(ports, pins, RS_GPIO_Port, RS_Pin, EN_GPIO_Port, EN_Pin, LCD_4_BIT_MODE);
	lcd = Lcd_create(lcd_ports, lcd_pins, RS_GPIO_Port, RS_Pin, E_GPIO_Port, E_Pin, LCD_4_BIT_MODE);

  /* USER CODE END 2 */

  /* Infinite loop */
  /* USER CODE BEGIN WHILE */

  // testing pins
//	HAL_TIM_Base_Start(&htim2);
//	HAL_TIM_PWM_Start(&htim2, TIM_CHANNEL_1);
//	HAL_TIM_PWM_Start(&htim2, TIM_CHANNEL_2);
//  HAL_GPIO_WritePin(MOTOR_1___IN1_GPIO_Port, MOTOR_1___IN1_Pin, GPIO_PIN_SET);
//  HAL_GPIO_WritePin(MOTOR_1___IN2_GPIO_Port, MOTOR_1___IN2_Pin, GPIO_PIN_SET);
//  HAL_GPIO_WritePin(MOTOR_2___IN3_GPIO_Port, MOTOR_2___IN3_Pin, GPIO_PIN_SET);
//  HAL_GPIO_WritePin(MOTOR_2___IN4_GPIO_Port, MOTOR_2___IN4_Pin, GPIO_PIN_SET);
//  HAL_GPIO_WritePin(VACUUM_GPIO_Port, VACUUM_Pin, GPIO_PIN_SET);
//  HAL_GPIO_WritePin(D4_GPIO_Port, D4_Pin, GPIO_PIN_SET);
//	HAL_GPIO_WritePin(D5_GPIO_Port, D5_Pin, GPIO_PIN_SET);
//	HAL_GPIO_WritePin(D6_GPIO_Port, D6_Pin, GPIO_PIN_SET);
//	HAL_GPIO_WritePin(D7_GPIO_Port, D7_Pin, GPIO_PIN_SET);
//	HAL_GPIO_WritePin(RS_GPIO_Port, RS_Pin, GPIO_PIN_SET);
//	HAL_GPIO_WritePin(E_GPIO_Port, E_Pin, GPIO_PIN_SET);
  while (1)
  {
		Lcd_clear_and_write(&lcd, "Waiting for map");

  	signal_cleaner_ready_for_map_receiving();
		MapInfo mapInfo;
		initialize_map(&huart2, &mapInfo);
		signal_map_received();

		Lcd_clear_and_write(&lcd, "Press the user button to start");
		// wait for the user to click on the start button
		while (HAL_GPIO_ReadPin(START_BUTTON_GPIO_Port, START_BUTTON_Pin) != GPIO_PIN_RESET);
		HAL_Delay(1000);
		//	PWM commands
		HAL_TIM_Base_Start(&htim2);
		HAL_TIM_PWM_Start(&htim2, TIM_CHANNEL_1);
		HAL_TIM_PWM_Start(&htim2, TIM_CHANNEL_2);

		MotorsInfo motorsInfo = {
				.left1_GPIOType = MOTOR_1___IN1_GPIO_Port, .left1_pin = MOTOR_1___IN1_Pin,
				.left2_GPIOType = MOTOR_1___IN2_GPIO_Port, .left2_pin = MOTOR_1___IN2_Pin,
				.right1_GPIOType = MOTOR_2___IN3_GPIO_Port, .right1_pin = MOTOR_2___IN3_Pin,
				.right2_GPIOType = MOTOR_2___IN4_GPIO_Port, .right2_pin = MOTOR_2___IN4_Pin,
		};
		CleanComponentsInfo cleanComponentsInfo = { .vacuum_GPIOType = VACUUM_GPIO_Port, .vacuum_pin = VACUUM_Pin };

		is_driving = true;

		Lcd_clear_and_write(&lcd, "Start cleaning");
		send_start_command(&huart2);
		int result_code = start_drive(&mapInfo, &is_obstacle_found, &huart2, &lcd, &motorsInfo, &cleanComponentsInfo);
		is_driving = false;
		send_end_command(&huart2, result_code);

		if (result_code != 0)
			signal_cleaner_error();

		char end_cleaning_message[33];
		snprintf(end_cleaning_message, 32, "Cleaning complete with code %d", result_code);
		Lcd_clear_and_write(&lcd, end_cleaning_message);

    /* USER CODE END WHILE */

    /* USER CODE BEGIN 3 */
		// deallocate the array representing the map
		free(mapInfo.map[0]);
		// deallocate the array of pointers to map rows
		free(mapInfo.map);

		HAL_TIM_PWM_Stop(&htim2, TIM_CHANNEL_1);
		HAL_TIM_PWM_Stop(&htim2, TIM_CHANNEL_2);

		HAL_Delay(2000); // wait for the user to see the result code
  }
  /* USER CODE END 3 */
}

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
/* USER CODE BEGIN 4 */

void HAL_GPIO_EXTI_Callback(uint16_t GPIO_Pin)
{
	if(GPIO_Pin == GPIO_PIN_9 && is_driving) // If The INT Source Is EXTI Line9 (A9 Pin)
	{
		HAL_NVIC_DisableIRQ(EXTI4_15_IRQn);
		is_obstacle_found = true;
	}
}

/* USER CODE END 4 */
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


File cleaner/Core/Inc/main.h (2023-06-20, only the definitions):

#define START_BUTTON_Pin GPIO_PIN_13
#define START_BUTTON_GPIO_Port GPIOC
#define MOTOR_1___IN1_Pin GPIO_PIN_0
#define MOTOR_1___IN1_GPIO_Port GPIOC
#define MOTOR_1___IN2_Pin GPIO_PIN_1
#define MOTOR_1___IN2_GPIO_Port GPIOC
#define MOTOR_2___IN3_Pin GPIO_PIN_2
#define MOTOR_2___IN3_GPIO_Port GPIOC
#define MOTOR_2___IN4_Pin GPIO_PIN_3
#define MOTOR_2___IN4_GPIO_Port GPIOC
#define MOTOR_1___Speed_Pin GPIO_PIN_0
#define MOTOR_1___Speed_GPIO_Port GPIOA
#define MOTOR_2___Speed_Pin GPIO_PIN_1
#define MOTOR_2___Speed_GPIO_Port GPIOA
#define DISTANCE_SENSOR_Pin GPIO_PIN_9
#define DISTANCE_SENSOR_GPIO_Port GPIOA
#define DISTANCE_SENSOR_EXTI_IRQn EXTI4_15_IRQn
#define VACUUM_Pin GPIO_PIN_10
#define VACUUM_GPIO_Port GPIOA
#define BUZZER_Pin GPIO_PIN_12
#define BUZZER_GPIO_Port GPIOA
#define D4_Pin GPIO_PIN_4
#define D4_GPIO_Port GPIOB
#define D5_Pin GPIO_PIN_5
#define D5_GPIO_Port GPIOB
#define D6_Pin GPIO_PIN_6
#define D6_GPIO_Port GPIOB
#define D7_Pin GPIO_PIN_7
#define D7_GPIO_Port GPIOB
#define E_Pin GPIO_PIN_8
#define E_GPIO_Port GPIOB
#define RS_Pin GPIO_PIN_9
#define RS_GPIO_Port GPIOB

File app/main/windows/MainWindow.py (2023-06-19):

import copy
from PySide6 import QtCore, QtWidgets

from main.util import MsgBoxUtil
from main.components import CellsGrid, SendMapDialog
from main.windows.RealTimeCleaningWindow import RealTimeCleaningWindow


class MainWindow(QtWidgets.QMainWindow):
    GRID_ROWS = 30
    GRID_COLUMNS = 30

    def __init__(self):
        super().__init__()
        self.setObjectName('main')

        self.setWindowTitle('Floor Cleaning Map Tool')
        self._create_grid()
        self._attach_menu()

    def _create_grid(self):
        self.cells_grid = CellsGrid.CellsGrid(
            MainWindow.GRID_ROWS, MainWindow.GRID_COLUMNS)
        self.setCentralWidget(self.cells_grid)

    def _attach_menu(self):
        # file menu
        fileMenu = self.menuBar().addMenu('&File')
        actionNew = fileMenu.addAction('&New grid')
        actionNew.triggered.connect(self._new_grid)

        actionSend = fileMenu.addAction('&Send')
        actionSend.triggered.connect(self._send)

        actionExit = fileMenu.addAction('&Exit')
        actionExit.triggered.connect(self._exit)

        # robot menu
        cleanerMenu = self.menuBar().addMenu('&Cleaner')
        actionPlaceCleaner = cleanerMenu.addAction('&Place Cleaner')
        actionPlaceCleaner.triggered.connect(self._place_cleaner)

    @QtCore.Slot()
    def _new_grid(self) -> None:
        self._create_grid()

    @QtCore.Slot()
    def _exit(self) -> None:
        self.close()

    @QtCore.Slot()
    def _send(self) -> None:
        dialog_send = SendMapDialog.SendMapDialog(self, self.cells_grid)
        sendResult = dialog_send.exec()

        if sendResult == QtWidgets.QDialog.DialogCode.Accepted:
            MsgBoxUtil.MsgBoxUtil.assert_with_timed_box('Send successful', 1500)

            realtime_map = copy.deepcopy(self.cells_grid.get_map())
            self.realtime_cleaning_window = RealTimeCleaningWindow(
                realtime_map, dialog_send.serial_connection_info, self)
            self.realtime_cleaning_window.open()
            self.realtime_cleaning_window.listen_for_cleaner_updates()

    @QtCore.Slot()
    def _place_cleaner(self) -> None:
        self.cells_grid.start_cells_cleaner_positioning()

        MsgBoxUtil.MsgBoxUtil.info_box('Place the cleaner by clicking on a cell')

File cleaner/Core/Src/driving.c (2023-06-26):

/*
 * driving.c
 *
 *  Created on: Aug 20, 2022
 *      Author: maluz
 */

#include <math.h>
#include <assert.h>
#include "types/map.h"
#include "stm32l0xx_hal.h"
#include "types/cleaner.h"
#include "types/utils.h"
#include "algorithm/shortest_path.h"
#include "map_communication.h"
#include "lcd.h"

// TODO: set based on motor rpm
int millis_to_turn = 750;
int millis_to_drive = 750;

static void get_next_position_while_driving_forward(CleanerInfo* cleanerInfo, MapPosition* target_position);
static bool drive_forward(CleanerInfo* cleanerInfo,
													bool* obstacle_found,
													bool cleaning_enabled,
													UART_HandleTypeDef *huart,
													Lcd_HandleTypeDef* lcd,
													MotorsInfo* motorsInfo);
static void turn_left(CleanerInfo* cleanerInfo, MotorsInfo* motorsInfo, Lcd_HandleTypeDef* lcd);
static void turn_right(CleanerInfo* cleanerInfo, MotorsInfo* motorsInfo, Lcd_HandleTypeDef* lcd);
static void enable_cleaning(CleanComponentsInfo* cleanComponentsInfo);
static void disable_cleaning(CleanComponentsInfo* cleanComponentsInfo);
static bool initialize_cleaner(MapInfo* mapInfo, CleanerInfo* cleanerInfo);
static bool find_first_around_cell(const MapPosition* start,
																	 const MapInfo* mapInfo,
																	 MapPosition* target,
																	 bool (*condition)(const MapInfo*, const MapPosition*));
static bool find_start_position(const MapInfo* mapInfo,
																  MapPosition* target_position);
static bool find_next_cell_while_cleaning(const CleanerInfo* cleanerInfo,
																					const MapInfo* mapInfo,
																					MapPosition* next_cell);
static bool move_cleaner_to(MapInfo* mapInfo,
														bool* obstacle_found,
														bool cleaning_enabled,
														UART_HandleTypeDef *huart,
														Lcd_HandleTypeDef* lcd,
														MotorsInfo* motorsInfo,
														CleanerInfo* cleanerInfo,
														const MapPosition* target_position);
static bool move_cleaner_to_adjacent_position(MapInfo* mapInfo,
																							bool* obstacle_found,
																							bool cleaning_enabled,
																							UART_HandleTypeDef *huart,
																							Lcd_HandleTypeDef* lcd,
																						  MotorsInfo* motorsInfo,
																						  CleanerInfo* cleanerInfo,
																						  MapPosition* target_position);

int start_drive(MapInfo* mapInfo,
								bool* obstacle_found,
								UART_HandleTypeDef *huart,
								Lcd_HandleTypeDef* lcd,
								MotorsInfo* motorsInfo,
								CleanComponentsInfo* cleanComponentsInfo) {
	CleanerInfo cleanerInfo;
	bool is_cleaner_found = initialize_cleaner(mapInfo, &cleanerInfo);
	if (!is_cleaner_found)
		return 1;

	MapPosition start_position;
	bool is_start_cell_found = find_start_position(mapInfo, &start_position);
	if (!is_start_cell_found)
		return 2;

	bool can_move_to_start_position = move_cleaner_to(mapInfo,
																										obstacle_found,
																										false,
																										huart,
																										lcd,
																										motorsInfo,
																										&cleanerInfo,
																										&start_position);

	if (!can_move_to_start_position)
		return 3;
	mapInfo->map[start_position.row][start_position.col] = ALREADY_CLEANED;
	// send this command to mark the first cell as cleaned
	send_new_cleaner_position_command(huart, start_position.row, start_position.col, true);

	bool is_cleaning_ongoing = true;
	while (is_cleaning_ongoing) {
		MapPosition next_cell;
		bool is_cell_available = find_next_cell_while_cleaning(&cleanerInfo, mapInfo, &next_cell);

		if (is_cell_available) {
			enable_cleaning(cleanComponentsInfo);
			move_cleaner_to_adjacent_position(mapInfo, obstacle_found, true, huart, lcd, motorsInfo, &cleanerInfo, &next_cell);
			disable_cleaning(cleanComponentsInfo);
		}
		else {
			is_cleaning_ongoing = find_first_around_cell(&cleanerInfo.position, mapInfo, &next_cell,
					lambda(bool, (const MapInfo* inner_mapInfo, const MapPosition* target_pos), {
						return inner_mapInfo->map[target_pos->row][target_pos->col] == TO_CLEAN;
					}));

			if (is_cleaning_ongoing) {
				bool can_reach_next_cell = move_cleaner_to(mapInfo, obstacle_found, false, huart, lcd, motorsInfo, &cleanerInfo, &next_cell);
				if (!can_reach_next_cell)
					return 4;

				mapInfo->map[next_cell.row][next_cell.col] = ALREADY_CLEANED;
				// send this command to mark the first cell after reaching a far cell as cleaned
				send_new_cleaner_position_command(huart, next_cell.row, next_cell.col, true);
			}
		}
	}

	return 0;
}

/*
 * move cleaner to a non-adjacent non-UNAVAILABLE position using a shortest path algorithm.
 * If an obstacle is found during the road, the shortest path is recomputed.
 * this method returns false only when there is no path to the specified target position
 * Precondition: the path is made of adjacent positions.
 */
static bool move_cleaner_to(MapInfo* mapInfo,
														bool* obstacle_found,
														bool cleaning_enabled,
														UART_HandleTypeDef *huart,
														Lcd_HandleTypeDef* lcd,
														MotorsInfo* motorsInfo,
														CleanerInfo* cleanerInfo,
														const MapPosition* target_position) {
	assert(mapInfo->map[target_position->row][target_position->col] != UNAVAILABLE);

	while (!are_MapPositions_equal(&cleanerInfo->position, target_position)) {
		MapPosition* path; size_t path_length;
		bool does_path_exist = find_best_path(&cleanerInfo->position, target_position, mapInfo, &path, &path_length);
		if (!does_path_exist)
			return false;

		bool is_move_successful;
		// the loop starts from 1 because the path includes the current position at index 0
		for (size_t i = 1; i < path_length; i++) {
			is_move_successful = move_cleaner_to_adjacent_position(mapInfo,
																														 obstacle_found,
																														 cleaning_enabled,
																														 huart,
																														 lcd,
																														 motorsInfo,
																														 cleanerInfo,
																														 &path[i]);
			if (!is_move_successful)
				break;
		}

		free(path);
	}

	return true;
}
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

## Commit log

2022-08-16 create new frame to place the grid
2022-08-16 add menu and fix absolute positioning for selection
    [Cell.py, CellsGrid.py]
2022-09-24 complete short path implementation
    [driving.c]
2022-09-25 [wip] start function to move cleaner on adjacent cell
    TODO:
    - obstacle_found should be reset if necessary
    - cleaner position should be changed inside drive_forward,
    when it happens
    [driving.c]
2022-09-27 complete start_drive, missing cleaning logic
    [driving.c]
2022-09-30 fix bug that did not let the algorithm finish
    the result of find_first_around_cell was negated incorrectly
    [driving.c]
2022-10-01 fix ALREADY_CLEANED after move_cleaner_to
    the first cell after a move must always be set to cleaned
    because only the target cell is set to ALREADY_CLEANED, not the
    initial one. add test with complex map
    [driving.c]
2022-10-04 #1: uart is coupled with DMA
    python app will send int as bytes, and not ascii characters.
    in this way, the DMA can move bytes directly to the allocated
    array representing the map. Optimization level changed to 02
    to get lambda support
2023-01-18 change MotorsInfo for L298N integration
2023-01-19 return to polling mode
    DMA was unnecessary given that I was indirectly polling on
    is_data_arrived.
    I have distinguished buzzer sounds for the phases when data
    are not arrived and when they are just arrived
    [cleaner.ioc, main.c, map_reader.c]
2023-01-19 fix MotorsInfo to accept GPIO_TypeDef pointers and add signal methods
    [driving.c, main.c]
2023-01-21 add start button
    [cleaning_robot.fzz]
2023-02-26 add interrupt for obstacle sensor
    [cleaning_robot.fzz]
2023-03-08 update fritzing schema and interrupt handling for distance sensor
    [cleaning_robot.fzz]
2023-05-28 add obstacle detection to report and changed its behavior
    the obstacle detection interrupt is enabled only when the cleaner moves,
    so only inside the drive_forward method
2023-06-18 add worker threads for realtime cleaning window
2023-06-19 fix real time color updates and fix send_command for movements
    wip: dma with transmit and find why obstacle is first message sent
    [RealTimeCleaningWindow.py, cleaner.ioc, driving.c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]
2023-06-20 add lcd messages and fix realtime cell coloring
    [RealTimeCleaningWindow.py, cleaner.ioc, driving.c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]
2023-06-20 fix bug for driving about obstacle cells
    obstacle cells were always overwritten by ALREADY_CLEANED
    when the cleaner was cleaning (and not just moving). The
    fix consists on updating a cell to ALREAD_CLEANED when the
    move is successful and the cleaning is enabled
    [driving.c]
2023-06-23 fix realtime messaging by adding starting move commands
    the cleaner now sends the starting position (while cleaning)
    so that the cells in the realtime windows are correctly updated
    [RealTimeCleaningWindow.py, driving.c]
2023-06-24 add architecture v2
    [cleaning_robot_v2.fzz]
2023-07-02 add DMA while transmitting with UART for realtime updates
    - The MX_DMA_Init(); must be placed before any other peripherals
    configuration
    - The USART2 global interrupt must be enable in order for the DMA
    to work
2023-07-02 clean code for DMA transmission on uart
    TODO: verify why the first move after start is skipped
    [map_communication.c]
2023-07-03 improve DMA transmit polling by checking the DMA TC flag

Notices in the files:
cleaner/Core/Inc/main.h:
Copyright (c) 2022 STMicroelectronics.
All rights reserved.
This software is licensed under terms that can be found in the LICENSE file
